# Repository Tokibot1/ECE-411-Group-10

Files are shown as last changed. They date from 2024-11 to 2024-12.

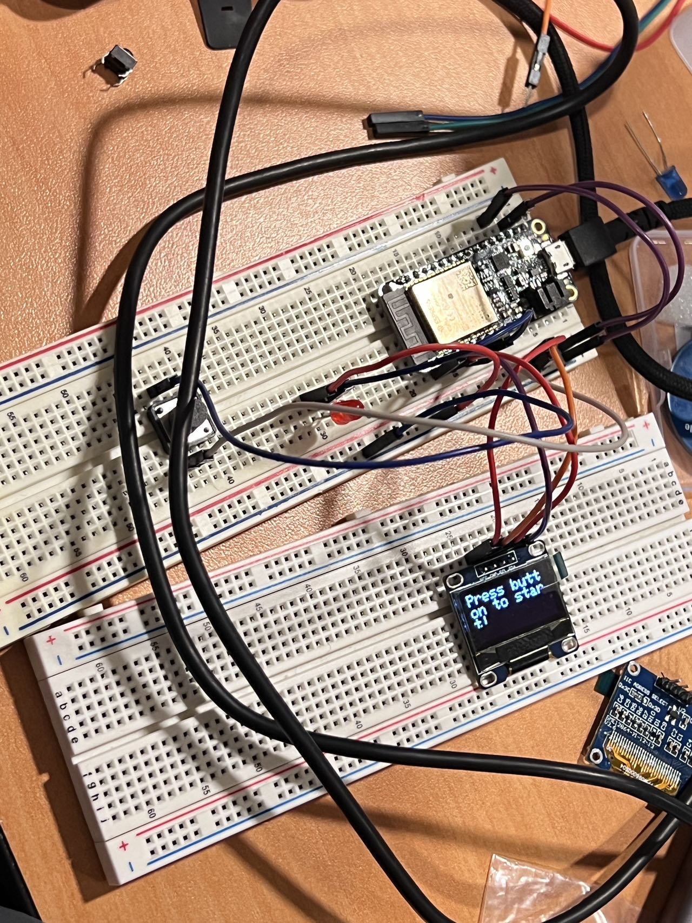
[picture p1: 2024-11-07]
Bread Board Prototype/Bread Board Prototype_2.jpg

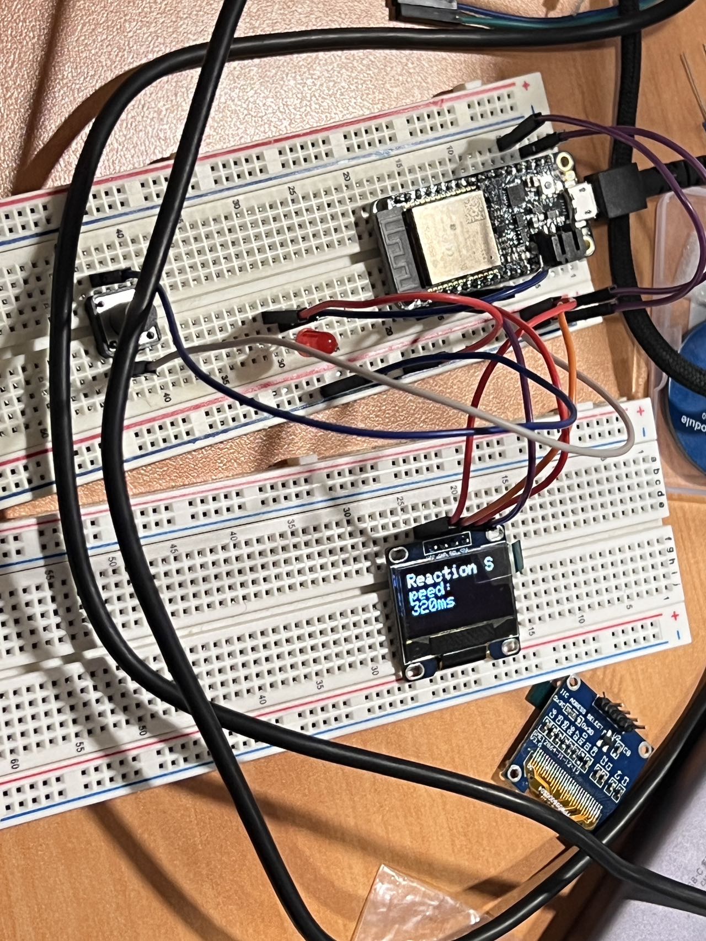
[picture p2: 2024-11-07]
Bread Board Prototype/Bread Board Prototype_1 .jpg

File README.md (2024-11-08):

# ECE-411-Group-10
Github repo for PSU ECE 411 Group 10
**The Portable Card Reaction Tester **
The Portable Card Reaction Tester and LED Memory Test Device is designed to provide users with two
interactive modes: measuring reaction time and testing memory retention. The compact, credit-card-sized
device features a joystick for selecting between these modes, four buttons, LEDs, and an LCD screen, offering
an engaging and versatile user experience.

Current Specifications:
1. Must be portable.
2. Must measure reaction times accurately.
3. Must have a screen to display the score.
4. Should be user-friendly.
5. Should initiate a countdown before testing.
6. Should have a switch to control power on/off.
7. May feature an aesthetically designed case.
8. May use low power.
9. May have different modes.

  **  This will be updated frequently**

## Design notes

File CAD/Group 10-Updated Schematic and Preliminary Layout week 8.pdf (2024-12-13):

1

### Updated Schematic and Preliminary Layout

Nov .20 , 2024
Version 1.2

Group 10
Team members: Xiang Li , Haoyang Han, Tony Tong , James Su , Danny Li

Because of the missing components of KICAD, we chose EasyEDA instead of KICAD

### Schematic

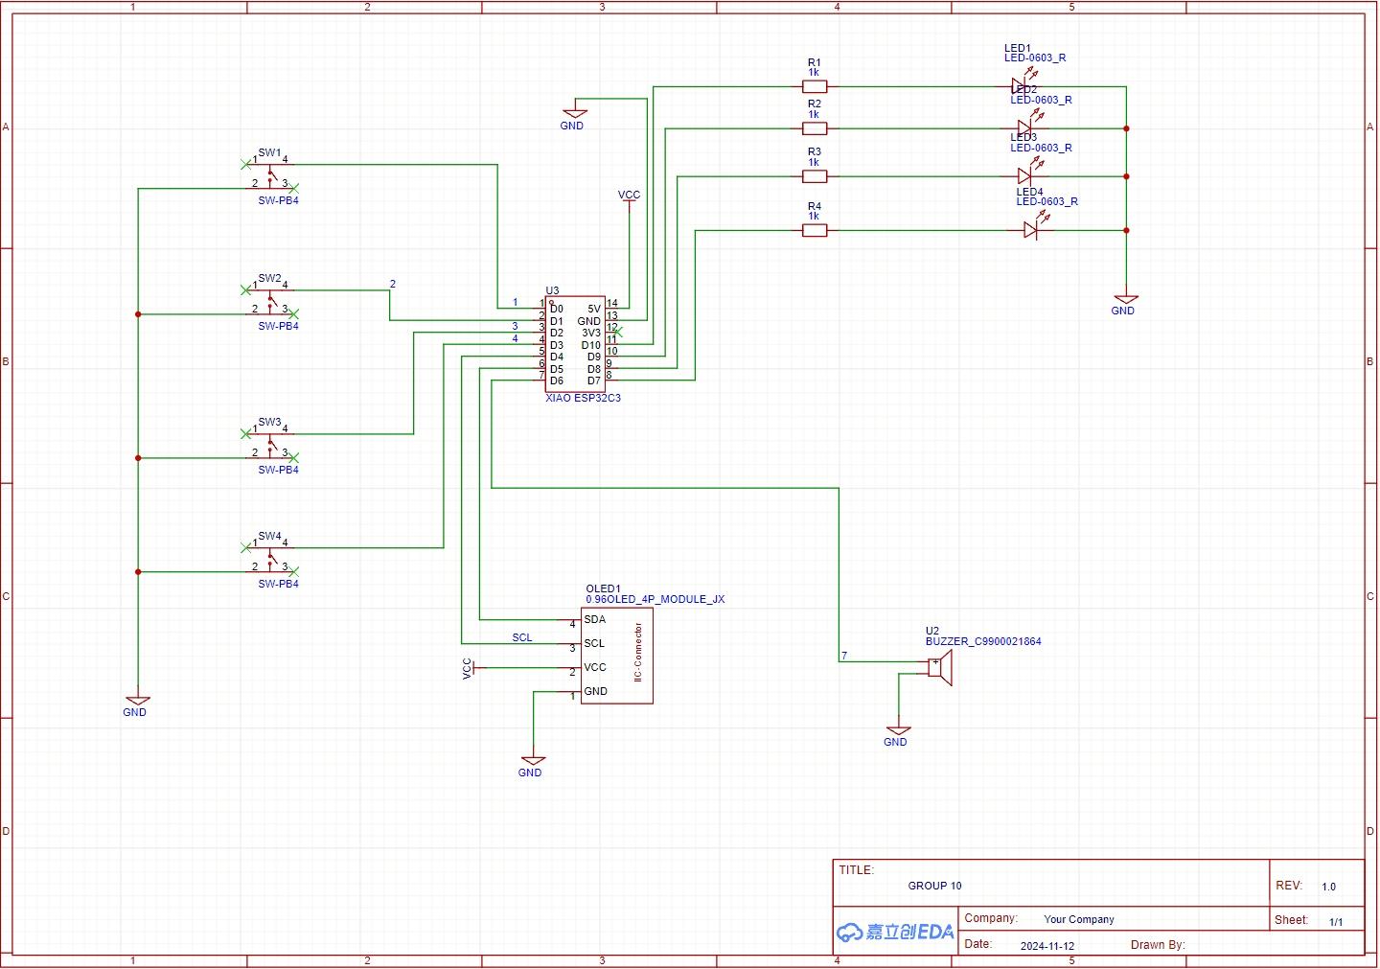
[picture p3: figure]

2

### Preliminary Layout

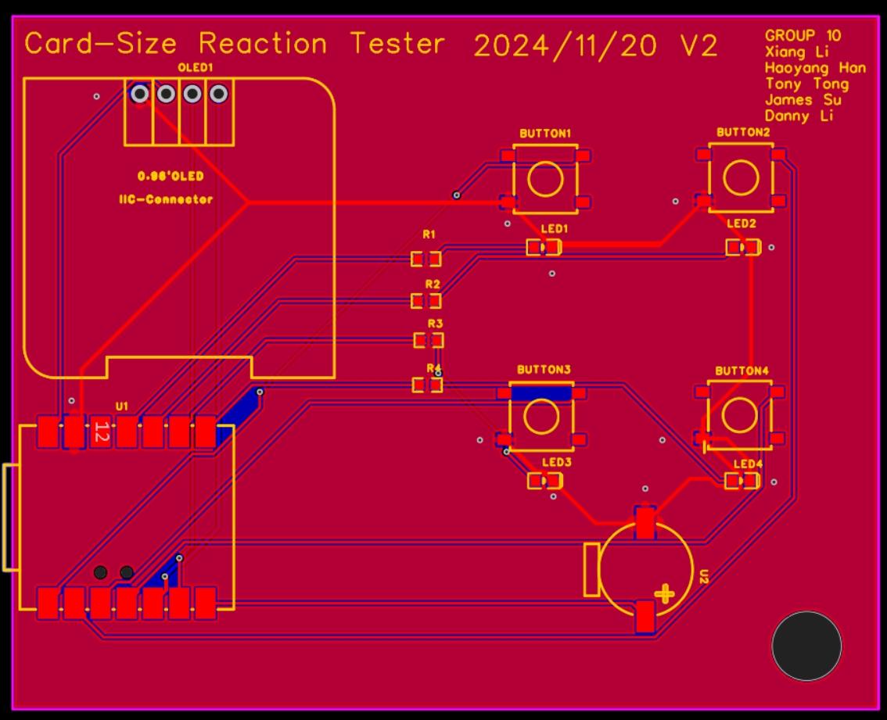
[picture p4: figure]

This week we have coppered the entire PCB to make it more complete, and added a "ground plane" according to your suggestion, making it more complete and effective.

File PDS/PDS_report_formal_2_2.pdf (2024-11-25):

# Card-size Reaction Test and LED Memory Test Device

Practicum Product Design Specification (PDS)

Team 10
Teammembers: Xiang Li, Haoyang Han, Tony Tong, James Su, Danny Li

November 6, 2024
Version: 2.1

# Contents

1

Maseeh College of Engineering and Computer Science | Portland State University

## 1 Executive Summary

The Portable Card-size Reaction Test and LED Memory Test Device is designed to implement two different interactive modes, namely reaction time measurement and memory retention testing. This handheld credit-card-sized device has been fitted with a joystick for mode selection, four buttons, LEDs, and an LCD screen to provide its users with an entertaining and diverse user experience.
In the Reaction Time Mode, the device can start a countdown while suddenly lighting up one of its LEDs. Immediately, the user should press the corresponding button as fast as possible and, on the screen, see the user’s reaction speed. These could be done several times and then the device will calculate and display the average reaction speed. Those are some really valuable data, even for users in different groups such as athletes, e-sport players, drivers, and every other human who wants to test their reflexes.
In the Memory Test Mode, the device challenges the player to remember an increased sequence of the flashing LEDs. The game starts by one LED lighting on and the user pressing the corresponding button. As it advances through levels, several LEDs blink in a random order; the player has to memorize and replay the correct sequence. Any wrong button pressed restarts the game, hence fun and challenging for the users. It is powered by the ESP32C3 microcontroller and housed in a custom 3D printed shell, making it portable and durable for convenience while carrying it anywhere at any time. Equipped with enhanced dual functionality, the Portable Card Reaction Tester and LED Memory Test Device come up with an effective and enjoyable device for testing both reaction times and memory, thus pleasing a wide range of user needs.

## 2 Market Analysis

### 2.1 Intended Users

- Athletes (for training)
- eSports players (to measure reflexes)
- F1-Drivers (to test reaction times for safety)
- General users (for personal interest and entertainment)

### 2.2 Competition

The current handheld reaction time devices are either larger in size or part of more expensive sport meters. Our device is uniquely portable, credit-card-sized, and cost-effective, hence fitting for the interests of both professional and casual users.

### 2.3 Price

The estimated price range is $30-$50, based on the cost of the components (microcontroller, sensors, LEDs, OLED display) and the 3D-printed casing. The main processor costs only $5, making the price competitive compared to larger and more complex reaction testing systems.

## 3 Requirements

1. Must be portable.
2. Must measure reaction times accurately.
3. Must have a screen to display the score.
4. Should be user-friendly.
5. Should initiate a countdown before testing.
6. Should have a switch to control power on/off.
Team 10 | Card-Size Reaction Tester and LED Memory Test Device | 2

7. Should have another function.
8. May feature an aesthetically designed case.
9. May use low power.
10. May have a menu.

## 4 System Architecture

### 4.1 Level 0 Block Diagram

Reaction Tester

Input | Output

Button Input Signal

Power, 3.7V DC

LED Light

Buzzer Sound Effect

Instructions and results form screen

### 4.2 Level 1 Block Diagram

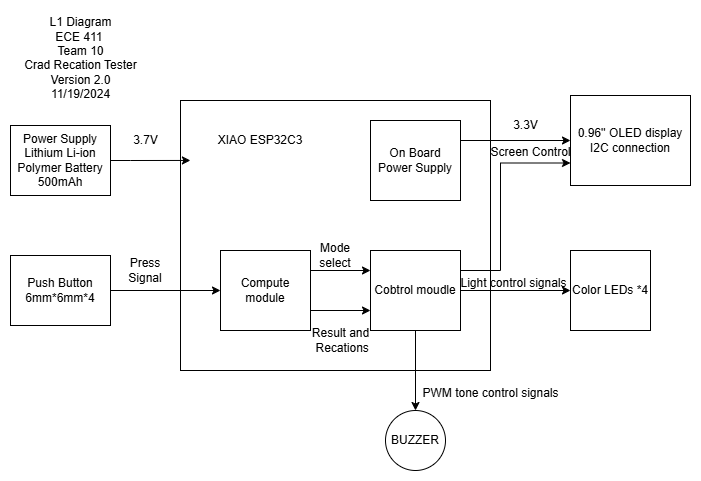
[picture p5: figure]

Team 10 | Card-Size Reaction Tester and LED Memory Test Device | 3

## 5 Design Specifications

- Sensors: Buttons
- Processor: ESP32C3
- Display: 0.96” OLED Screen
- Sound: Buzzer
- Power: Lithium Li-ion Polymer Battery
- Development Environment: Arduino, VS Code
- Case: 3D printed
- Purpose: Effective and compact design
Team 10 | Card-Size Reaction Tester and LED Memory Test Device | 4

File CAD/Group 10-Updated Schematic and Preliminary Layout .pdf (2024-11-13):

1

### Updated Schematic and Preliminary Layout

Nov .07 , 2024
Version 1.1

Group 10
Team members: Xiang Li , Haoyang Han, Tony Tong , James Su , Danny Li

### Schematic

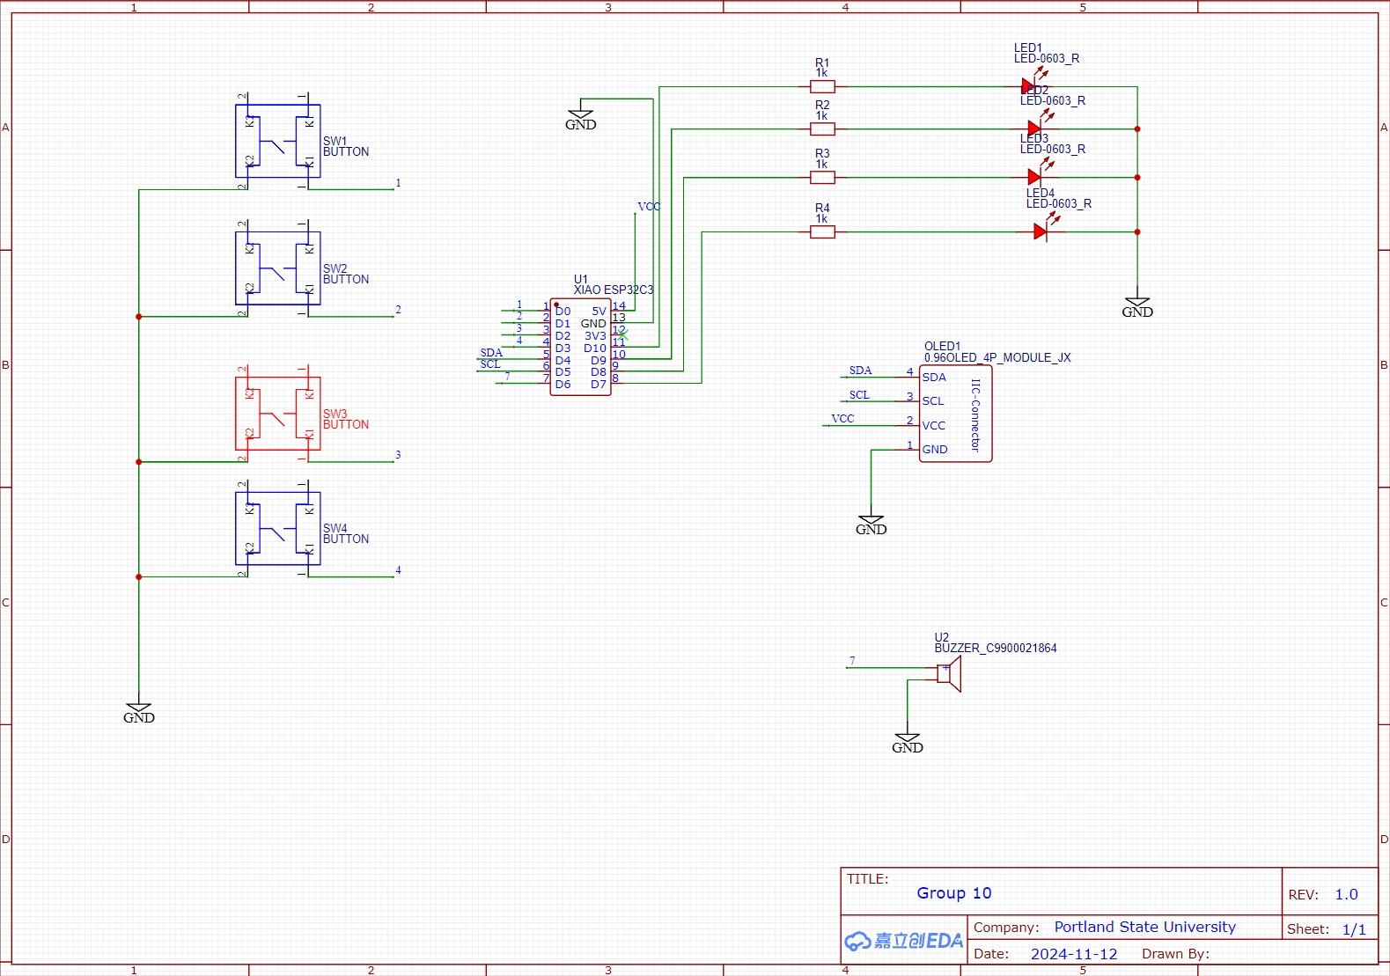
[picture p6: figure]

2

P

r

### eli

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
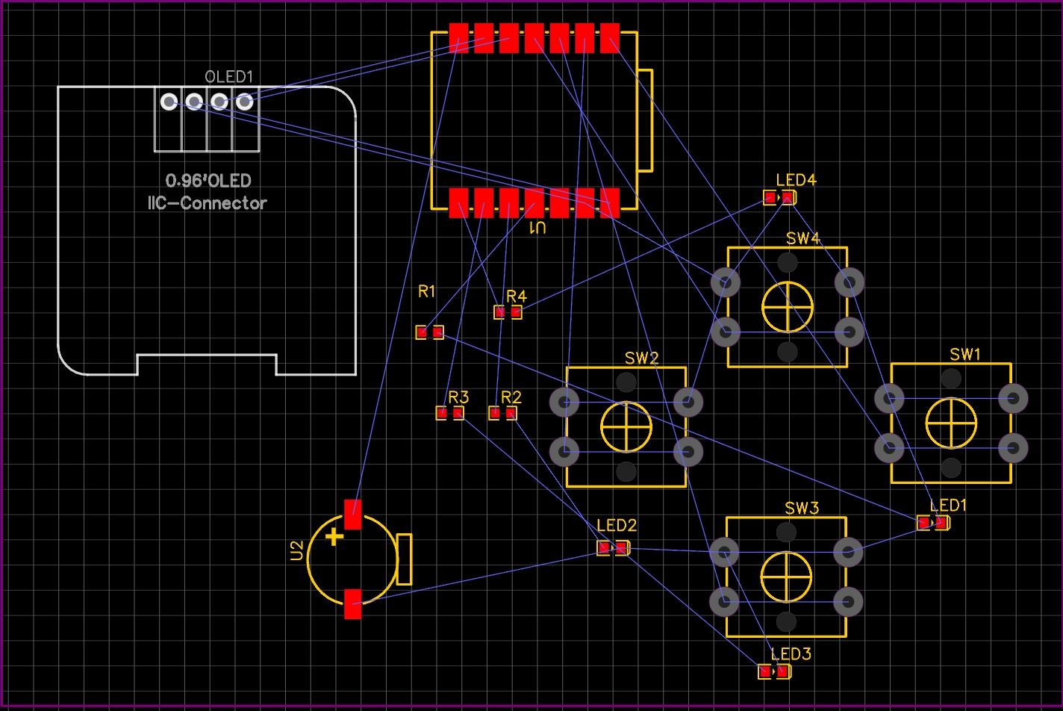
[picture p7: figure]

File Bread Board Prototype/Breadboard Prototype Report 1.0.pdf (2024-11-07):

# Breadboard Prototype

11/6/2024
Team 10: Xiang Li , Haoyang Han, Tony Tong , James Su , Danny Li

We start building our real circuit step by step, starting with testing each part of the circuit first and then adding them together to do the function. Note that the board we actually want, Seeed Studio XIAO ESP32C3, is still on delivery, so we have to use another board(Adafruit ESP32 Feather) to test the components first.

# Testing: I2C connection screen

We first tried to test the screen and see if we could drive it correctly. This is harder than we thought because the cheap component we bought actually doesn’t have any documentation support, so we need to try to find a library that will drive it correctly. After some testing we finally get it working, showing the correct text we want in the right place.

# Testing: Buttons and LEDs

Then we want to test if the buttons are working properly. This took some amount of time because at first the LEDs somehow didn't work at all, ant buttons cannot react correctly. We wrote some small test program for this part and we got it working with a signal button and LED. In our plan we want at least 4 groups of them and we need to implement that latter.

# Final test: Interact with each other

We set up one LED and one Button, and we want it to work like: press the button to start the game, after the LED turns on. Click the button immediately and then the screen can show your reaction time. This is only part of the final proposal. We will add up to 4 buttons and more functions later. We had some hard time on the code and testing, and we finally got it worth it at some point, but it is overall very buggy. We still need to consider a lot of timing details and button debouncing.

1

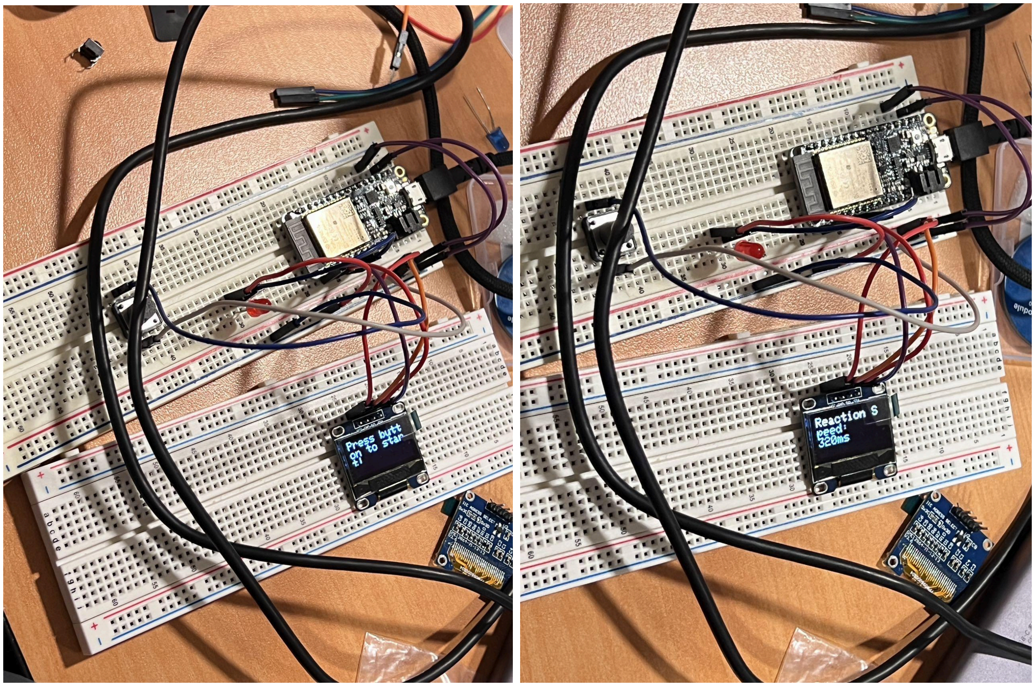
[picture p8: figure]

# Summary and future plans

We get a small part of our product working, but it is just at the beginning. We will need to add a joystick to choose mode or do other interesting things and build more groups of LEDs and buttons. We’ll keep working and try to make more progress next week.

2

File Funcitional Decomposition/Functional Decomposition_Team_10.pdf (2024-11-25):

# Functional Decomposition

Team 10: Xiang Li, Haoyang Han, Tony Tong, James Su, Danny Li 11/13/2024
Version: 1.1

# L0 Diagram

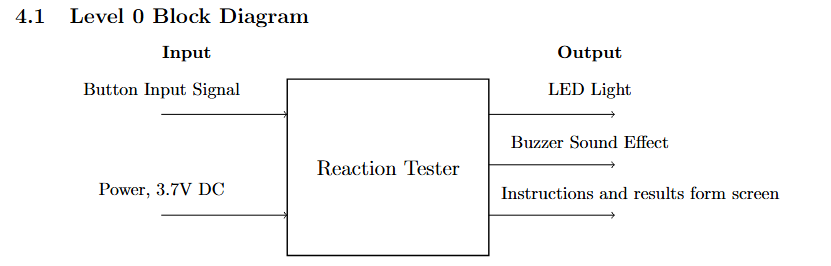
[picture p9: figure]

L0 shows the basic input and output of our device, its power will be from a 3.7V Lithium Li-ion Polymer Battery, and the buttons are the main thing the player interacts with.
The LED lights and Data form the screen will give the user a clear guidance about what they are going to do and what they’ll get. The Buzzer is used to add sound effects to make it better.

1

# L1 Diagram

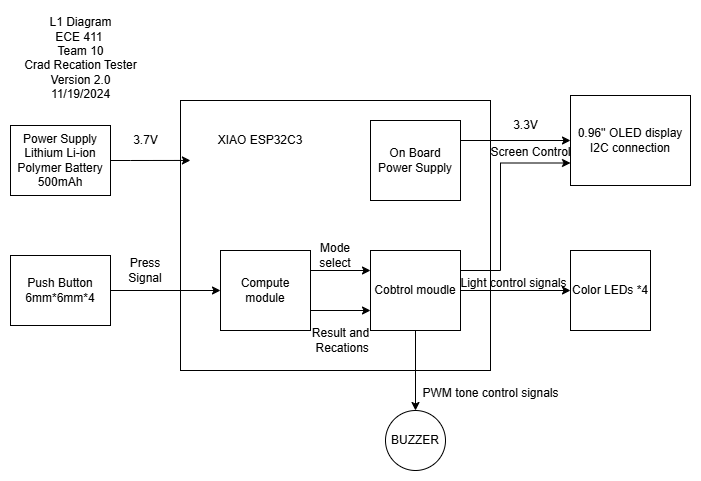
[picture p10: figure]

The L1 diagram shows more details about the device, and labels all the function of input and output signals. This device basically receives output from the buttons and shows the results after competition. Note that for the power supply, the controller is connected to a 3.7V battery, but the other components are powered by the board is 3.3V

2

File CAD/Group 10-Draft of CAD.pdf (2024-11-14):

1

### Draft of CAD

Nov .13 , 2024
Version 1.2

Group 10
Team members: Xiang Li , Haoyang Han, Tony Tong , James Su , Danny Li

### Schematic


2

L

a

y

o

u

t

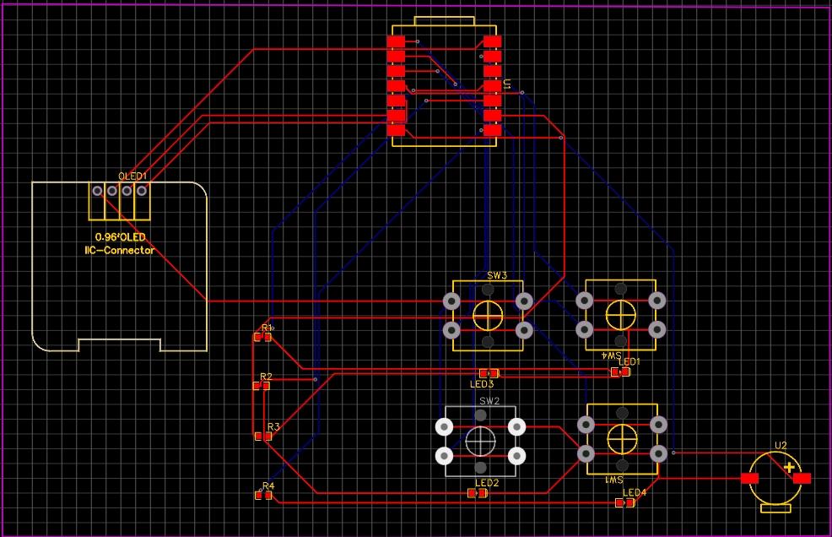
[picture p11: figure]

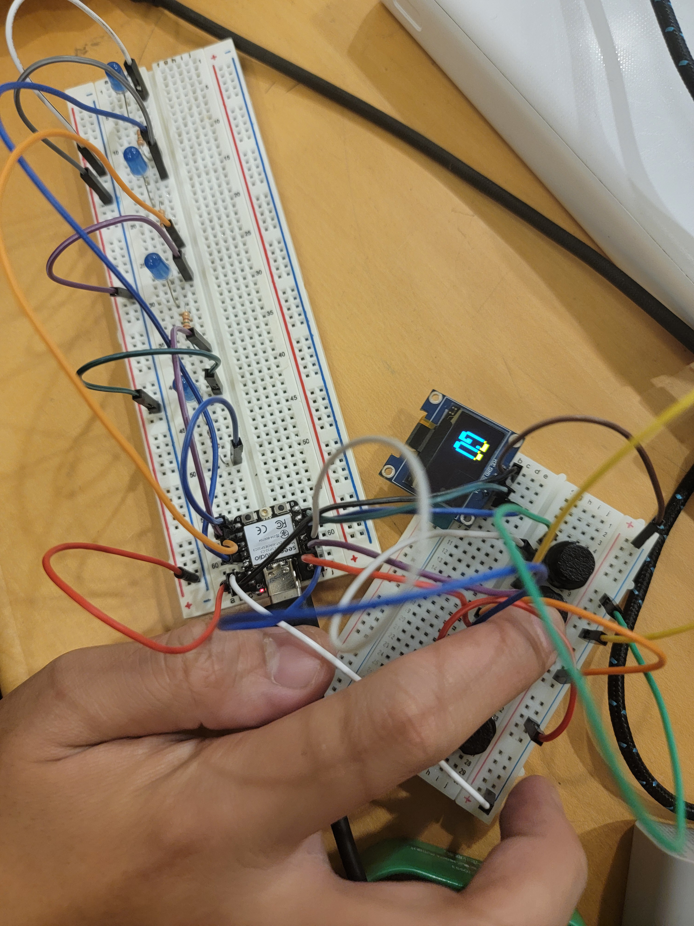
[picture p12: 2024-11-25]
Bread Board Prototype/Version 2.0.jpg

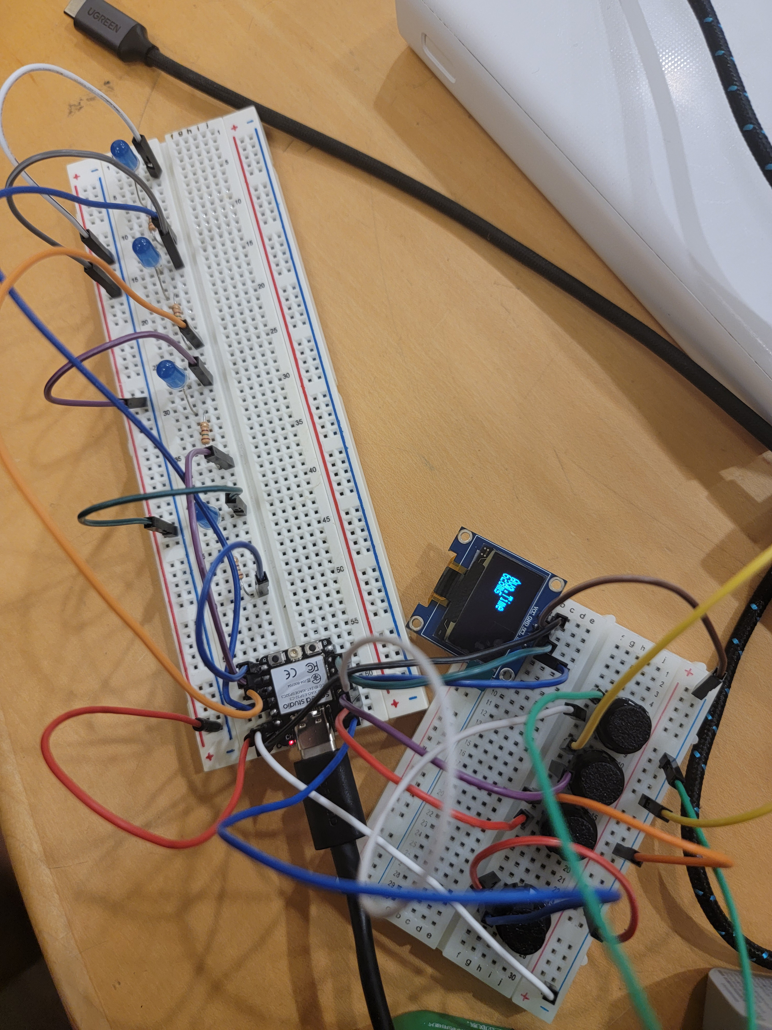
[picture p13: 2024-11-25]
Bread Board Prototype/Version 2.0 (2).jpg

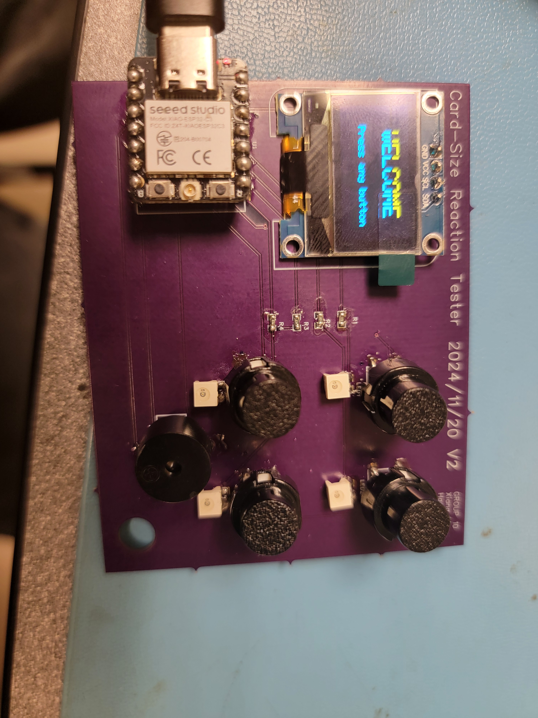
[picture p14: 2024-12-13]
Bread Board Prototype/PCB_V.jpg

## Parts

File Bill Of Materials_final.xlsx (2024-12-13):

Bill Of Materials for: Team 10
Last modified: Nov 21, 2024
PCB version: 2.0.0
BOM revision: 2.0.0 |  | P/NP | = Place/Not Place (components marked NP are Not stuffed on the board)
Cnt | Part References | P/NP | Mfg | Mfg PN | Description | Dist | Dist Part Number | Cost Ea. | Cost Total
1 | U1 | P | Seeed Technology Co., Ltd | 113991054 | ESP32-C3 ESP32-C Transceiver; 802.11 b/g/n (Wi-Fi, WiFi, WLAN), Bluetooth® 5.x (BLE) 2.4GHz Evaluation Board | Digi-Key | 1597-113991054-ND | $4.99 | $4.99
4 | SW1, SW2, SW3, SW4 | P | C&K | D6R90 F2 LFS | SWITCH PUSH SPST-NO 0.1A 32V | Digi-Key | 401-1995-ND | $1.56 | $6.24
1 | LED1 | P | ams-OSRAM USA INC. | A67K-E1F2-25-0-2-R33-1 | Green 560mm LED Indication - Discrete 1.8V 2-SMD, Boomerang | Digi-Key | 475-2758-1-ND | $0.20 | $0.20
1 | LED2 | P | ams-OSRAM USA INC. | A67K-E1F2-25-0-2-R33-0 | Green 560mm LED Indication - Discrete 1.8V 2-SMD, Boomerang | Digi-Key | 475-1252-1-ND | $0.20 | $0.20
1 | LED3 | P | ams-OSRAM USA INC. | A67K-E1F2-25-0-2-R33-1 | Green 560mm LED Indication - Discrete 1.8V 2-SMD, Boomerang | Digi-Key | 475-2545-1-ND | $0.20 | $0.20
1 | LED4 | P | ams-OSRAM USA INC. | A67K-E1F2-25-0-2-R33-2 | Green 560mm LED Indication - Discrete 1.8V 2-SMD, Boomerang | Digi-Key | 475-1248-1-ND | $0.20 | $0.20
1 | BZ1 | P | Gearbox Labs | PART PASSIVE BUZZER 5V | Buzzers Piezo 5 V Through Hole PC Pins | Digi-Key | 4166-PARTPASSIVEBUZZER5V-ND | $1.00 | $1.00
1 | Power Source | P | Adafruit Industries LLC | 3898 | 3.7 V Lithium-Ion Battery Rechargeable (Secondary) 400mAh | Digi-Key | 1528-2731-ND | $6.95 | $6.95
1 | LCD Display | P | HiLetgo | SSD1306 | HiLetgo 0.96" SSD1306 I2C IIC SPI Serial 128X64 OLED LCD Display 4 Pin Font Color Blue | Digi-Key | UG-2864HSWEG01-ND | $6.99 | $6.99
1 | Cable | P | Adafruit Industries LLC | 261 | JST PH 2-Pin Cable - Female Connector 100mm, CABLE ASSY JST PH 2PIN 4" | Digi-Key | 1528-1126-ND | $0.75 | $0.75
1 | Power Switch | P | Adafruit Industries LLC | 805 | Adafruit Accessories Breadboard Friendly SPDT Slide Switch | Digi-Key | 485-805-ND | $0.95 | $0.95
10 | SMD Resistor | P | BOURNS | CRM1206-JW-1R0ELF | SMD Current Sense Resistors, CRM Series, 1 ohm, 500 mW, - 5%, 200 V, 1206 [3216 Metric] RoHS Compliant: Yes | Digi-Key | 1623729-1-ND | $0.10 | $1.00
 |  |  |  |  |  |  |  | TOTAL: | $29.67
VERSION INFO
Rev | Date | Notes
1.0.0 | 2024-11-13 | Rough draft of board
1.1.0 | 2024-11-18 | Add the details of LED,resistors, etc.
1.1.1 | 2024-11-19 | Add the Rocker switch, resistors, SPDT switch etc.
2.0.0 | 2024-11-21 | The final version

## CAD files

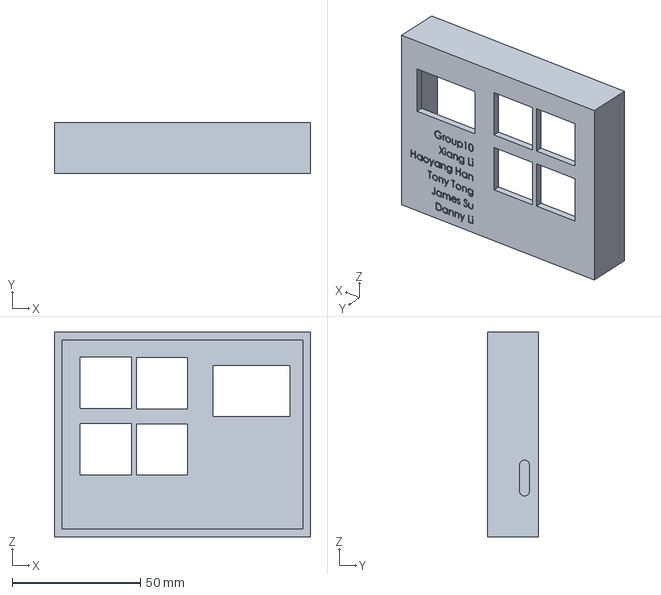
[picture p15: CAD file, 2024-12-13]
3D-printing model/box new new.3MF
100.0 x 20.0 x 80.0 mm

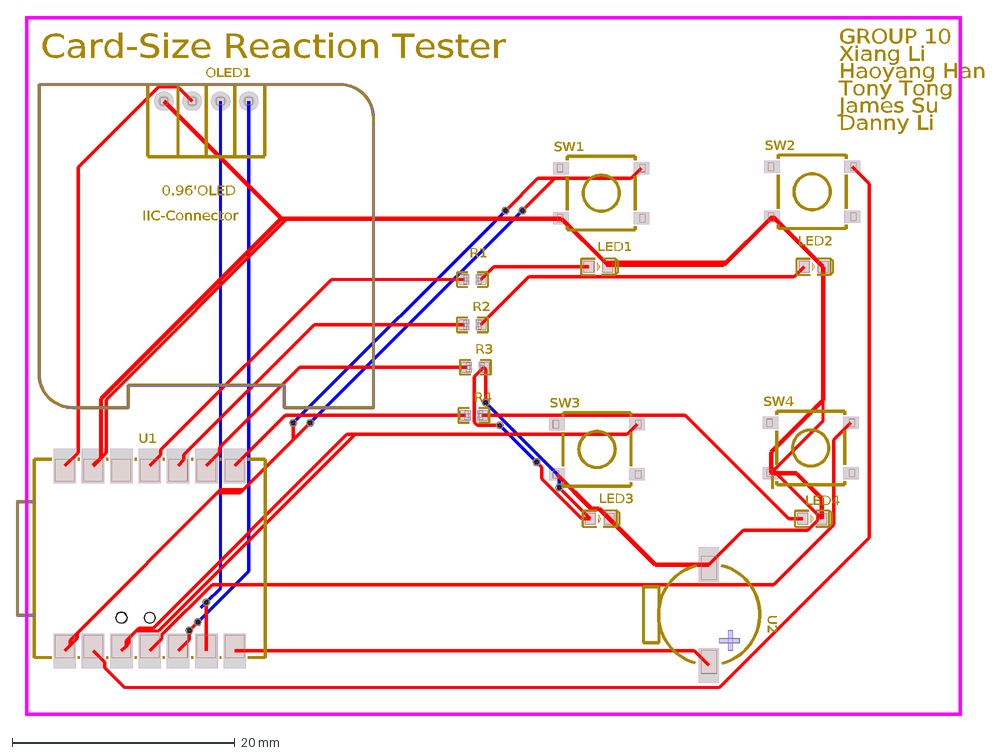
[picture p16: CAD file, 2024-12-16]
CAD/DXF_1-PCB_PCB_GROUP 10_2024-12-15_AutoCAD2013.dxf
GROUP 10
Xiang Li
Haoyang Han
Tony Tong
James Su
Danny Li
Card-Size Reaction Tester
LED1
LED2
LED3
LED4
IIC-Connector
0.96'OLED
OLED1
R1
R2
R3
R4
SW1
SW2
SW3
SW4
U1
U2

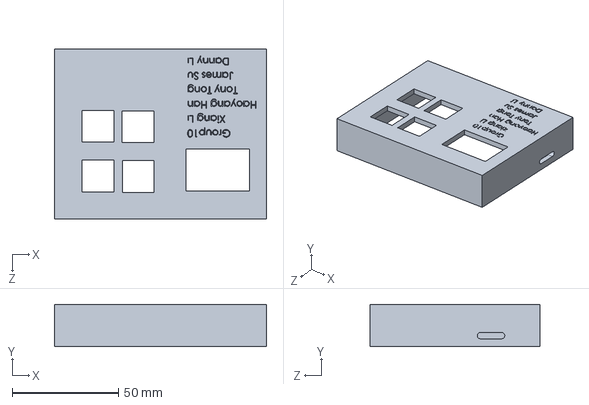
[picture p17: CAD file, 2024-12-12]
3D-printing model/box new.SLDPRT
100.0 x 20.0 x 80.0 mm

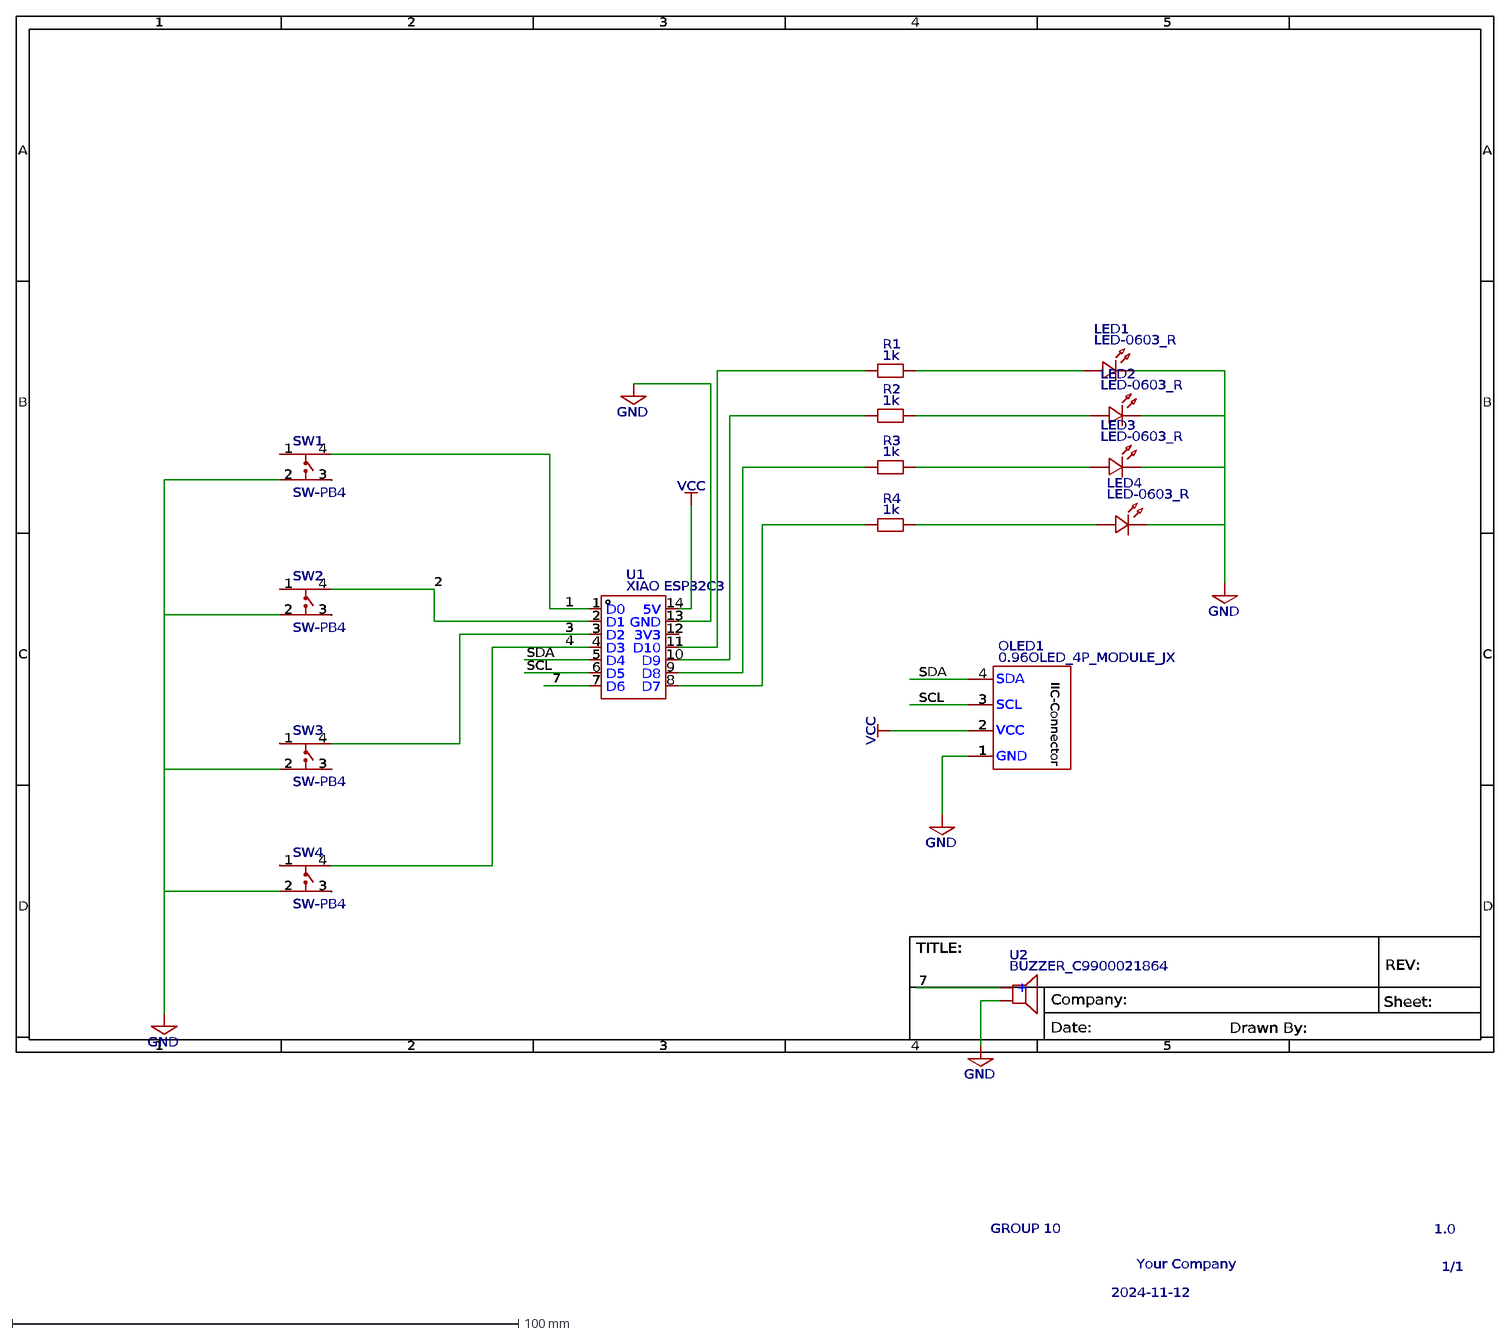
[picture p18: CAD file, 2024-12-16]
CAD/1_Sheet_1.dxf
GROUP 10
1.0
2024-11-12
1/1
Your Company
A
B
C
D
1
2
3
4
5
TITLE:
REV:
Date:
Sheet:
Drawn By:
Company:
XIAO ESP32C3
U1
D0
D1
D2
D3
D4
D5
6
D6
7
D7
8
D8
9
D9
10
D10
11
3V3
12
GND
13
5V
14
0.96OLED_4P_MODULE_JX
OLED1
IIC-Connector
SDA
SCL
VCC
1k
R1
R2
R3
R4
BUZZER_C9900021864
U2
+
LED-0603_R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

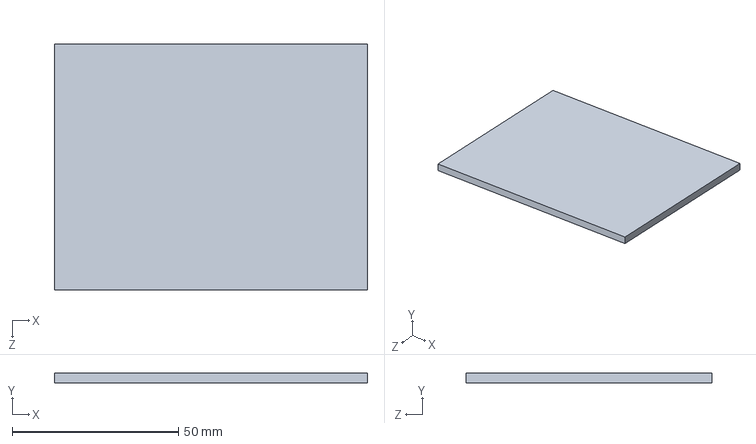
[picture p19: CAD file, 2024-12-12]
3D-printing model/di.SLDPRT
94.0 x 3.00 x 74.0 mm

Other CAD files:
3D-printing model/box.SLDPRT
3D-printing model/box new.3MF
3D-printing model/box.3MF
3D-printing model/di.3MF

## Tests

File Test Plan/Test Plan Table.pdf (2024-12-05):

# Detailed Test Plans

12/3/2024
Team 10 Xiang Li, Haoyang Han, Tony Tong, James Su, Danny Li
Version 1.2
Test Author: Xiang Li
Test Case Name: | OLED Screen UI Testing | Test ID #: | Functional 1-5
Description: | Based on the final hardware, test the software functions, including the menu, the main reaction test function and the expanded functions. Code is in Github/testcode/Testcode_1.3.ino | Type: | □ white box □ black box □ ________

Tester Information
| Name of Tester: | Xiang Li, Haoyang Han , Tony Tong | Date: | 12/2/2024
| HW/SW Version: | BreadBoard Final Version 1.0 | Time: | 2 Hours
| Setup: | The completed circuit with 4 led, 4 buttons, OLED screen, Buzzer connected to the processor, proposing to test the UI shown by the screen and if it can output the correct result from software settings. The processor is connected to the computer for power and debugging.
S T E P | Action | Expected Result | P A S S | F A I L | N / A | Comments
1 | Upload the code to XIAO ESP32C3 | The Screen lights up and shows the welcome Screen. | √ | | | The Welcome Screen can be more informative, more than “Welcome”
2 | Click any button to enter the Menu | The output on the Screen moved to MENU | √
3 | Use two buttons as UP and Down | The “cursor “ of the menu should be controlled by the two buttons. | √ | | | Later add the background highlight to make it more visible.
4 | Use Button to choose the desired function- Reaction test | The result go into the Reaction Game welcome page | √
5 | Start the game by clicking button | Show the Count Down “3,2,1” | √ | | | Later change the size of the numbers.

6 | Push the corresponding button with the light LED | After pushing, the LED is off, and reaction time is recorded. | √
7 | After the number of cycles, show result | The average reaction time shown on Screen | √ | Make the text size LARGER
8 | Back to MENU, can choose function again | Show the Menu and can interact with it again. | √

9
| Overall test result: The Basic function is working as expected, the UI is informative and clear, and can work normally as expected.

Test Author: Haoyang Han , Tony Tong

Test Case Name: | The Reaction Test and Memory game reaction | Test ID #: | Functional 1-2
Description: | The buttons and LEDs should perform differently on different modes. This is to test the action of LED ,buttons and results shown on the screen. | Type: | □ white box □ black box □ _____________

Tester Information

| Name of Tester: | Xiang Li, Haoyang Han , Tony Tong | Date: | 12/3/2024
| HW/SW Version: | BreadBoard Final Version 1.0 | Time: | 2 hours
| Setup: | The completed circuit with 4 led, 4 buttons, OLED screen, Buzzer connected to the processor, proposing to test the UI shown by the screen and if it can output the correct result from software settings. The processor is connected to the computer for power and debugging.
T | INPUTS | EXPECTED OUTPUTS | P | F | N | Comments

E S T | | | A S S | A I L | / A
1 | In Reaction test, click the Button of the corresponding LED | One LED off, the other ON | √ | | | Can have some future improvements
2 | In Reaction test, click the different Button of the corresponding LED | LED still on, hold the state | √
3 | In the memory test, click the button in the right order shown before. | Pass this round, go into the next round. | √
4 | In the memory test, click the button in the different order shown before. | Shown “GAME OVER” | √
| Overall test result: For Different inputs in different modes, it responds correctly.

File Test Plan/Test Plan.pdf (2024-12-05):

# Test Plan

12/4/2024
Team 10 Xiang Li, Haoyang Han, Tony Tong, James Su, Danny Li Version 1.0

# Unit Test

1. Test Lipo battery supplies 3.7V.
2. Test buttons are connected to the right pair of pins.
3. Test buttons can change state when pushed.
4. Test button push can be detected by the processor.
5. Test LED can be lit up by the processor output pin.
6. Test the resistance of the resistors are correct.
7. Test the 0.96’’ OLED display can light up
8. Test the buzzer, make sure it can sound.
9. Test the processor can be connected to the port of the computer.
10. Test program can be uploaded on the processor.

# Verification test

1. Test the LED can light up in control of the processor.
2. Test the button pressed is recognized by the processor.
3. Test the OLED can show the required instructions.
4. Test the processor can control the 4 LEDs randomly light up one by one.
5. Test the LEDs can be turned off by pressing the button.
6. Test the processor can measure the time between LED light up and button pressed.
7. Test the OLED screen can show the Countdown. (3,2,1)
8. Test the OLED screen can show results of different modes.
9. Test the buzzer so it can sound at the correct time and control.
10. Test the button can be used to switch between functions.
11. Test the Menu can show the selections and act properly.
12. Test the Memory game performs well.

1

# Validation tests

1. Verify that the device is portable and fits within a credit card's dimensions.
2. Confirm the device accurately measures reaction times to within ± 10 ms.
3. Validate that scores are legibly displayed on the OLED screen.
4. Ensure the user interface is intuitive and easy to operate.
5. Verify the countdown before tests is consistent and accurate.
6. Check that the device powers on/off with a single switch.
7. Ensure both the Reaction Tester and LED Memory Test Modes operate seamlessly.
8. Test the other additional functions correctly.

In this testing phase, we will first focus on verifying the basic functionalities of the device to ensure that its core components and system operate as designed. This includes testing the power supply, buttons, LEDs, OLED screen, buzzer, and processor for their fundamental performance and interactions. Once the foundational features are confirmed to be stable, we will proceed to test the overall system performance, including random LED control, reaction time measurement, memory game logic, and the user interface experience.

After the basic functionality tests demonstrate stability, we plan to evaluate the scalability of the device and explore the addition and optimization of new features. We may improve the user interface, enhance the entertainment value of the game modes, or explore more efficient power management methods. All these optimizations will be carried out while ensuring the stability of the existing functionalities.

2

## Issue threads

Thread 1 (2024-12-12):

PCB components miss match with The Screen

Tokibot1, 2024-12-12:
In the PCB circuit, the OLED screen has different pinout orders as the component we have. There are a lot of similar of this kind of screens out on the Market, they look the same but some have different VCC and GND pin orders. We have a mismatch on that so the first one on our PCB burns out! I've already bought some new pieces that matches !

Tokibot1, 2024-12-12:
We need to test the new screen first as it has a different address

Tokibot1, 2024-12-13:
Remember although the backside of the screen writes address 0x78, the real address is 0x3C

Closed 2024-12-13.

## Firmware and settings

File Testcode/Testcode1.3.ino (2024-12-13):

// Test code 1.3+
// Added a new game mode and improved the menu
// details:
// 1. Added a new game mode: Memory Game
// 2. Improved the menu by adding a border and highlighting the selected option
// 3. Added a welcome screen at the beginning
// 4. Added a countdown before starting the game
#include <SPI.h>
#include <Wire.h>
#include <Adafruit_GFX.h>
#include <Adafruit_SSD1306.h>

#define SCREEN_WIDTH 128 // OLED display width, in pixels
#define SCREEN_HEIGHT 64 // OLED display height, in pixels
#define OLED_RESET     -1 // Reset pin #
#define SCREEN_ADDRESS 0x3C ///< I2C address
#define SSD1306_NO_SPLASH 
Adafruit_SSD1306 display(SCREEN_WIDTH, SCREEN_HEIGHT, &Wire, OLED_RESET);

// Define push buttons and LEDs pins
const int buttonPins[4] = {D0, D1, D2, D3};
const int ledPins[4] = {D7, D8, D9, D10};

// 菜单相关变量
const char* menuOptions[] = {"1. Reaction Game", "2. Jumping Block", "3. Memory Game"};
int selectedOption = 0;        // 当前选中的菜单选项
const int totalOptions = 3;    // 菜单选项总数
bool inMenu = true;            // 是否在菜单中

// 函数声明
void waitForAnyButtonPress();
void startCountdown();
void reactionGame();
void dinoGame();
void memoryGame();
void displayWelcomeScreen();
void showMenu();

void setup() {
  // 初始化串口通信，方便调试
  Serial.begin(9600);

  // 初始化按钮为输入模式，并启用内部上拉电阻
  for (int i = 0; i < 4; i++) {
    pinMode(buttonPins[i], INPUT_PULLUP);
  }

  // 初始化LED为输出模式，并设置为低电平（熄灭）
  for (int i = 0; i < 4; i++) {
    pinMode(ledPins[i], OUTPUT);
    digitalWrite(ledPins[i], LOW);
  }

  // 初始化OLED显示屏
  if (!display.begin(SSD1306_SWITCHCAPVCC, SCREEN_ADDRESS)) {
    Serial.println("SSD1306 allocation failed");
    for (;;); // 如果初始化失败，进入死循环
  }
  display.clearDisplay();

  // 显示欢迎界面
  displayWelcomeScreen();

  // 显示菜单
  showMenu();
}

void loop() {
  // 主程序循环
  if (!inMenu) {
    // 根据选中的选项执行对应的功能
    switch (selectedOption) {
      case 0:
        reactionGame(); // 反应游戏
        break;
      case 1:
        dinoGame(); // 小恐龙游戏
        break;
      case 2:
        memoryGame(); // 记忆力游戏
        break;
      default:
        break;
    }
    // 执行完毕后返回菜单
    inMenu = true;
    showMenu();
  }
}

// 等待任意按钮按下
void waitForAnyButtonPress() {
  bool buttonPressed = false;
  while (!buttonPressed) {
    for (int i = 0; i < 4; i++) {
      if (digitalRead(buttonPins[i]) == LOW) {
        buttonPressed = true;
        delay(200); // 消抖延迟
        break;
      }
    }
  }
}

// 开始游戏前的倒计时
void startCountdown() {
  display.clearDisplay();
  display.setTextSize(2);
  display.setTextColor(WHITE);
  for (int i = 3; i > 0; i--) {
    display.clearDisplay();
    display.setCursor(50, 20);
    display.print(i);
    display.display();
    delay(1000);
  }
  display.clearDisplay();
  display.display();
}

// 显示欢迎界面
void displayWelcomeScreen() {
  display.clearDisplay();
  display.setTextSize(2);
  display.setTextColor(WHITE);
  display.setCursor(25, 10);
  display.println("WELCOME");
  display.setTextSize(1);
  display.setCursor(30, 40);
  display.println("Press any button");
  display.display();
  waitForAnyButtonPress();
  display.clearDisplay();
}

// 美化菜单并显示
void showMenu() {
  while (inMenu) {
    // 清空显示屏
    display.clearDisplay();

    // 绘制菜单边框
    display.drawRect(0, 0, SCREEN_WIDTH, SCREEN_HEIGHT, WHITE);

    // 设置文本属性
    display.setTextSize(1);
    display.setTextColor(WHITE);

    // 显示菜单标题
    display.setCursor(30, 2);
    display.println("Select Game");

    // 显示每个菜单选项
    for (int i = 0; i < totalOptions; i++) {
      if (i == selectedOption) {
        // 高亮当前选中的选项
        display.fillRect(10, 15 + i * 15, 108, 12, WHITE);
        display.setTextColor(BLACK); // 黑色文字，白色背景
      } else {
        display.setTextColor(WHITE); // 白色文字，黑色背景
      }
      display.setCursor(15, 17 + i * 15);
      display.println(menuOptions[i]);
    }

    // 更新显示屏
    display.display();

    // 处理按钮输入
    if (digitalRead(buttonPins[1]) == LOW) { // 下一项
      selectedOption = (selectedOption + 1) % totalOptions;
      delay(200); // 消抖延迟
    }
    if (digitalRead(buttonPins[2]) == LOW) { // 上一项
      selectedOption = (selectedOption - 1 + totalOptions) % totalOptions;
      delay(200); // 消抖延迟
    }
    if (digitalRead(buttonPins[0]) == LOW) { // 选择当前选项
      inMenu = false;
      delay(200); // 消抖延迟
    }
  }
}

// 第一个游戏模式：反应游戏
void reactionGame() {
  display.clearDisplay();
  display.setTextSize(1);
  display.setTextColor(WHITE);
  display.setCursor(30, 0);
  display.println("Press any");
  display.println("button to");
  display.setTextSize(2);
  display.setCursor(25, 20);
  display.print("START");
  display.display();
  waitForAnyButtonPress();

  startCountdown();

  unsigned long reactionTimes[4];
  int currentRound = 0;
  while (currentRound < 4) {
    // 随机等待一段时间
    delay(random(1000, 3000));

    // 随机选择一个LED点亮
    int randomLED = random(0, 4);
    digitalWrite(ledPins[randomLED], HIGH);
    unsigned long startTime = millis();

    // 等待玩家按下对应的按钮
    while (digitalRead(buttonPins[randomLED]) == HIGH) {
      // 等待正确的按钮被按下
    }
    unsigned long endTime = millis();
    digitalWrite(ledPins[randomLED], LOW);

    // 记录反应时间
    reactionTimes[currentRound] = endTime - startTime;
    currentRound++;
    delay(500); // 等待0.5秒再进入下一轮
  }

  // 计算平均反应时间
  unsigned long totalTime = 0;
  for (int i = 0; i < 4; i++) {
    totalTime += reactionTimes[i];
  }
  unsigned long averageTime = totalTime / 4;

  // 显示平均反应时间
  display.clearDisplay();
  display.setCursor(15, 20);
  display.setTextSize(2);
  display.setTextColor(WHITE);
  display.print("Avg:");
  display.print(averageTime);
  display.println("ms");
  display.display();

  // 等待玩家按下按钮返回菜单
  waitForAnyButtonPress();
}

// 第二个游戏模式：小恐龙游戏
void dinoGame() {
  // 初始化游戏参数
  const int jumpButtonPin = buttonPins[0]; // 跳跃按钮引脚
  bool gameRunning = true;
  int dinoX = 10; // 恐龙的X坐标
  int dinoY = 48; // 恐龙的Y坐标
  int dinoWidth = 10; // 恐龙的宽度
  int dinoHeight = 15; // 恐龙的高度
  int groundLevel = 48; // 地面Y坐标
  bool isJumping = false; // 是否在跳跃
  float jumpVelocity = 0; // 跳跃速度
  float gravity = 0.5; // 重力加速度
  float jumpStrength = -8; // 跳跃初速度

  unsigned long score = 0; // 分数
  int obstacleSpeed = 2; // 初始障碍物速度
  const int maxObstacleSpeed = 6; // 最大障碍物速度
  unsigned long lastObstacleTime = millis();
  int obstacleGap = 1500; // 初始障碍物间隔（毫秒）

  // 障碍物结构体
  struct Obstacle {
    int x;
    int y;
    int width;
    int height;
  };
  const int maxObstacles = 2; // 同屏最大障碍物数量
  Obstacle obstacles[maxObstacles];
  // 初始化障碍物数组
  for (int i = 0; i < maxObstacles; i++) {
    obstacles[i].x = -1; // 设置为屏幕外
  }

  // 游戏主循环
  while (gameRunning) {
    // 清空显示屏
    display.clearDisplay();

    // 更新分数
    score++;

    // 根据分数增加障碍物速度，设定上限
    if (score % 1000 == 0 && obstacleSpeed < maxObstacleSpeed) {
      obstacleSpeed++;
      if (obstacleGap > 800) {
        obstacleGap -= 100; // 减少障碍物间隔，最低800ms
      }
    }

    // 绘制地面
    display.drawLine(0, groundLevel + dinoHeight, SCREEN_WIDTH, groundLevel + dinoHeight, WHITE);

    // 绘制小恐龙（简单的矩形代替）
    display.fillRect(dinoX, dinoY, dinoWidth, dinoHeight, WHITE);

    // 绘制障碍物
    for (int i = 0; i < maxObstacles; i++) {
      if (obstacles[i].x >= 0) {
        display.fillRect(obstacles[i].x, obstacles[i].y, obstacles[i].width, obstacles[i].height, WHITE);
      }
    }

    // 显示分数
    display.setTextSize(1);
    display.setTextColor(WHITE);
    display.setCursor(80, 0);
    display.print("Score: ");
    display.print(score / 10);

    // 更新显示屏
    display.display();

    // 处理跳跃输入
    if (digitalRead(jumpButtonPin) == LOW && !isJumping) {
      isJumping = true;
      jumpVelocity = jumpStrength; // 跳跃初速度
    }

    // 更新恐龙位置
    if (isJumping) {
      dinoY += jumpVelocity;
      jumpVelocity += gravity;

      // 检查是否落地
      if (dinoY >= groundLevel) {
        dinoY = groundLevel;
        isJumping = false;
      }
    }

    // 生成新障碍物
    if (millis() - lastObstacleTime > obstacleGap) {
      lastObstacleTime = millis();
      for (int i = 0; i < maxObstacles; i++) {
        if (obstacles[i].x < 0) {
          obstacles[i].x = SCREEN_WIDTH;
          obstacles[i].width = random(8, 16); // 随机宽度
          obstacles[i].height = random(10, 20); // 随机高度
          obstacles[i].y = groundLevel + dinoHeight - obstacles[i].height;
          break;
        }
      }
    }

    // 更新障碍物位置
    for (int i = 0; i < maxObstacles; i++) {
      if (obstacles[i].x >= 0) {
        obstacles[i].x -= obstacleSpeed;
        // 检查是否出了屏幕
        if (obstacles[i].x + obstacles[i].width < 0) {
          obstacles[i].x = -1; // 移出屏幕，等待重新使用
        } else {
          // 检查碰撞
          int dinoLeft = dinoX;
          int dinoRight = dinoLeft + dinoWidth;
          int dinoTop = dinoY;
          int dinoBottom = dinoTop + dinoHeight;

          int obstacleLeft = obstacles[i].x;
          int obstacleRight = obstacleLeft + obstacles[i].width;
          int obstacleTop = obstacles[i].y;
          int obstacleBottom = obstacleTop + obstacles[i].height;

          bool collision = !(dinoRight < obstacleLeft || dinoLeft > obstacleRight || dinoBottom < obstacleTop || dinoTop > obstacleBottom);
          if (collision) {
            gameRunning = false;
            break;
          }
        }
      }
    }

    delay(20); // 控制游戏速度
  }

  // 显示游戏结束和分数
  display.clearDisplay();
  display.setTextSize(2);
  display.setTextColor(WHITE);
  display.setCursor(15, 10);
  display.println("Game Over");
  display.setTextSize(1);
  display.setCursor(25, 40);
  display.print("Score: ");
  display.print(score / 10);
  display.display();
  delay(3000);

  // 返回菜单
  waitForAnyButtonPress();
}

// 第三个游戏模式：记忆力游戏
void memoryGame() {
  display.clearDisplay();
  display.setTextSize(1);
  display.setTextColor(WHITE);
  display.setCursor(20, 0);
  display.println("Memory Game");
  display.setCursor(10, 20);
  display.println("Follow the sequence");
  display.display();
  waitForAnyButtonPress();

  const int sequenceLength = 5;
  int sequence[sequenceLength];
  bool gameRunning = true;

  // 生成随机序列
  for (int i = 0; i < sequenceLength; i++) {
    sequence[i] = random(0, 4);
  }

  // 游戏主循环
  for (int round = 1; round <= sequenceLength && gameRunning; round++) {
    // 显示当前轮数
    display.clearDisplay();
    display.setTextSize(1);
    display.setCursor(35, 0);
    display.print("Round ");
    display.println(round);
    display.display();
    delay(1000);

    // 播放序列
    for (int i = 0; i < round; i++) {
      digitalWrite(ledPins[sequence[i]], HIGH);
      delay(500);
      digitalWrite(ledPins[sequence[i]], LOW);
      delay(250);
    }

    // 接收玩家输入
    for (int i = 0; i < round; i++) {
      bool buttonPressed = false;
      while (!buttonPressed) {
        for (int j = 0; j < 4; j++) {
          if (digitalRead(buttonPins[j]) == LOW) {
            buttonPressed = true;
            if (j != sequence[i]) {
              gameRunning = false;
            }
            delay(200); // 消抖
            break;
          }
        }
      }
      if (!gameRunning) {
        break;
      }
    }
    delay(500);
  }

  // 显示游戏结束或胜利
  display.clearDisplay();
  display.setTextSize(2);
  display.setTextColor(WHITE);
  if (gameRunning) {
    display.setCursor(10, 20);
    display.println("You Win!");
  } else {
    display.setCursor(5, 20);
    display.println("Game Over");
  }
  display.display();
  delay(3000);

  // 返回菜单
  waitForAnyButtonPress();
}

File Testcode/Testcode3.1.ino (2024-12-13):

// NEW bug: the reaction game is going more rounds if the wrong button
// is pressed. The game should only go to the next round if the correct
// DIno game could pause


// Reverted debounce method to previous version
// Added walls in the Snake Game
// Moved score display to the upper right corner in Snake Game
// Screen address is 0x3C

#include <SPI.h>
#include <Wire.h>
#include <Adafruit_GFX.h>
#include <Adafruit_SSD1306.h>

#define SCREEN_WIDTH 128  // OLED display width, in pixels
#define SCREEN_HEIGHT 64  // OLED display height, in pixels
#define OLED_RESET     -1 // Reset pin #
#define SCREEN_ADDRESS 0x3C // I2C address
#define SSD1306_NO_SPLASH 

Adafruit_SSD1306 display(SCREEN_WIDTH, SCREEN_HEIGHT, &Wire, OLED_RESET);

const int buzzerPin = D6; // Buzzer connected to D6

// Define push buttons and LEDs pins
const int buttonPins[4] = {D0, D1, D2, D3};
const int ledPins[4] = {D7, D8, D9, D10};

// Menu variables
const char* menuOptions[] = {"1. Reaction Game", "2. Jumping Dino", "3. Memory Game", "4. Snake Game", "5. Settings"};
int selectedOption = 0;        // Currently selected menu option
const int totalOptions = 5;    // Total number of menu options
bool inMenu = true;            // Whether in menu
int menuOffset = 0;            // Menu scroll offset

// Game settings
int reactionGameRounds = 4;
int memoryGameRounds = 5;
int snakeGameSpeed = 200; // Delay in milliseconds
int dinoGameDifficulty = 1; // Difficulty level

// Function declarations
void waitForAnyButtonPress();
void startCountdown();
void reactionGame();
void dinoGame();
void memoryGame();
void snakeGame();
void settingsMenu();
void adjustSetting(int settingIndex);
void displayWelcomeScreen();
void showMenu();

void setup() {
  // Initialize serial communication for debugging
  Serial.begin(9600);

  // Initialize buttons as input with internal pull-up resistors
  for (int i = 0; i < 4; i++) {
    pinMode(buttonPins[i], INPUT_PULLUP);
  }

  // Initialize LEDs as output and turn them off
  for (int i = 0; i < 4; i++) {
    pinMode(ledPins[i], OUTPUT);
    digitalWrite(ledPins[i], LOW);
  }

  // Initialize buzzer
  pinMode(buzzerPin, OUTPUT);

  // Initialize OLED display
  if (!display.begin(SSD1306_SWITCHCAPVCC, SCREEN_ADDRESS)) {
    Serial.println("SSD1306 allocation failed");
    for (;;); // Loop forever if initialization fails
  }
  display.clearDisplay();

  // Display welcome screen
  displayWelcomeScreen();

  // Show menu
  showMenu();
}

void loop() {
  // Main program loop
  if (!inMenu) {
    // Execute the selected option
    switch (selectedOption) {
      case 0:
        reactionGame(); // Reaction Game
        break;
      case 1:
        dinoGame(); // Jumping Dino Game
        break;
      case 2:
        memoryGame(); // Memory Game
        break;
      case 3:
        snakeGame(); // Snake Game
        break;
      case 4:
        settingsMenu(); // Settings
        break;
      default:
        break;
    }
    // Return to menu after game ends
    inMenu = true;
    showMenu();
  }
}

// Wait for any button to be pressed
void waitForAnyButtonPress() {
  bool buttonPressed = false;
  while (!buttonPressed) {
    for (int i = 0; i < 4; i++) {
      if (digitalRead(buttonPins[i]) == LOW) {
        buttonPressed = true;
        delay(200); // Debounce delay
        break;
      }
    }
  }
}

// Countdown before starting game
void startCountdown() {
  display.clearDisplay();
  display.setTextSize(2);
  display.setTextColor(WHITE);
  for (int i = 3; i > 0; i--) {
    display.clearDisplay();
    display.setCursor(50, 20);
    display.print(i);
    display.display();
    tone(buzzerPin, 1000, 200); // Play tone
    delay(1000);
  }
  display.clearDisplay();
  display.display();
}

// Display welcome screen
void displayWelcomeScreen() {
  display.clearDisplay();
  display.setTextSize(2);
  display.setTextColor(WHITE);
  display.setCursor(25, 10);
  display.println("WELCOME");
  display.setTextSize(1);
  display.setCursor(20, 40);
  display.println("Press any button");
  display.display();
  waitForAnyButtonPress();
  display.clearDisplay();
}

// Display menu with scrolling support
void showMenu() {
  while (inMenu) {
    // Clear display
    display.clearDisplay();

    // Draw menu border
    display.drawRect(0, 0, SCREEN_WIDTH, SCREEN_HEIGHT, WHITE);

    // Set text properties
    display.setTextSize(1);
    display.setTextColor(WHITE);

    // Display menu title
    display.setCursor(30, 2);
    display.println("Select Game");

    // Scroll menu if needed
    if (selectedOption < menuOffset) {
      menuOffset = selectedOption;
    } else if (selectedOption >= menuOffset + 4) {
      menuOffset = selectedOption - 3;
    }

    // Display menu options
    for (int i = menuOffset; i < min(menuOffset + 4, totalOptions); i++) {
      if (i == selectedOption) {
        // Highlight selected option
        display.fillRect(10, 15 + (i - menuOffset) * 12, 108, 12, WHITE);
        display.setTextColor(BLACK);
      } else {
        display.setTextColor(WHITE);
      }
      display.setCursor(15, 17 + (i - menuOffset) * 12);
      display.println(menuOptions[i]);
    }

    // Update display
    display.display();

    // Handle button input
    if (digitalRead(buttonPins[1]) == LOW) { // Next option
      selectedOption = (selectedOption + 1) % totalOptions;
      delay(200); // Debounce delay
    }
    if (digitalRead(buttonPins[2]) == LOW) { // Previous option
      selectedOption = (selectedOption - 1 + totalOptions) % totalOptions;
      delay(200); // Debounce delay
    }
    if (digitalRead(buttonPins[0]) == LOW) { // Select current option
      inMenu = false;
      delay(200); // Debounce delay
    }
  }
}
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

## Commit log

2024-10-24 The first version of our PDS
    Our first PDS！ The online word version please check google shared file
2024-11-07 Test update
    Changed PDS V1.0, First breadboard test is done, the basic function that is using one button and one led is partly finish.
2024-11-07 First Breadboard prototype Report
    Finished the report
2024-11-13 Create Group 10-Updated Schematic and Preliminary Layout .pdf
2024-11-14 Create Group 10-Draft of CAD.pdf
2024-11-20 Create Testcode_1.0.ino
    Updated Test code 1.0，this version already has the basic function
2024-11-20 Bill of Materials Update
    [Bill Of Materials.xlsx]
2024-11-25 Organize and 2.0 Code
    I organized the folders and wrote the text code 2.0, adding other functions. still needs test.
    [Week5-1.kicad_sch]
2024-12-13 Create box new new.3MF
    [box new new.3MF]
2024-12-13 Prototype upload
2024-12-13 Update Bill Of Materials_final.xlsx
    [Bill Of Materials_final.xlsx]
2024-12-13 Create Group 10-Updated Schematic and Preliminary Layout week 8.pdf
2024-12-16 PCB Engineering Files
    [1_Sheet_1.dxf, DXF_1-PCB_PCB_GROUP 10_2024-12-15_AutoCAD2013.dxf]
